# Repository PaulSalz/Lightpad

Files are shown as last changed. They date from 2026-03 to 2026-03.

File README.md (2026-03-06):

<div align="center">
<h1 align="center"><b>LightPad</b></h1>
DIY MIDI Controller to use with the Midi2LR Plugin

<picture>
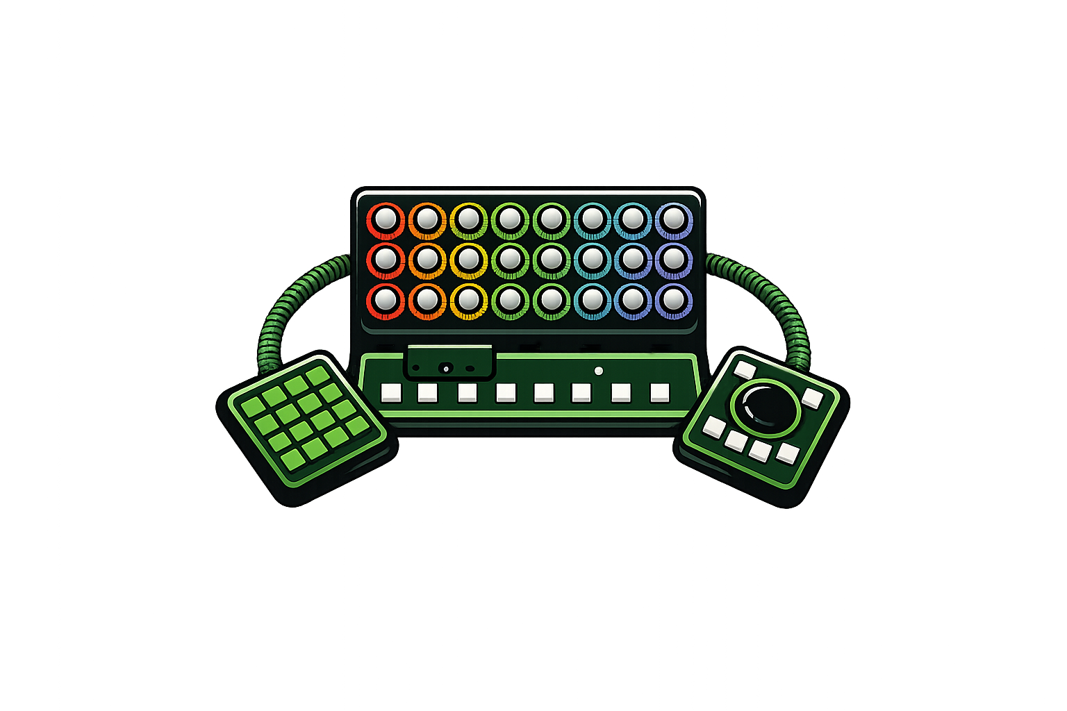
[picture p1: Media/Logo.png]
LightPad_Logo

</picture>
</div>
<br>

<picture>

</picture>

# Main features
- **[24x Interrupt-Driven Encoders](https://github.com/PaulSalz/lightpad/blob/main/Media/test_enc_led.jpg)**  
     - 3x8 RGB-illuminated Push-Button Encoders for all the main sliders, Lights, HSl, Details, ColorGrading, Effects...
- **[4x4 Button Matrix](https://github.com/PaulSalz/lightpad/blob/main/Media/top_view.jpg)**  
     - 16x RGB Buttons for easy Preset, Shortcut access
- **[Main Module](https://github.com/PaulSalz/lightpad/blob/main/Media/test_all.jpg)**  
     - 2x8 Buttons for switching Layers and often used features
- **[Media/ Culling Pad](https://github.com/PaulSalz/lightpad/blob/main/Media/side_view.jpg)**  
     - 8x RGB Buttons and an ANO Directional Navigation and Scroll Wheel to cull and navigate your library
- **[Force Feedback](https://github.com/PaulSalz/lightpad/blob/main/Media/test_all.jpg)**  
     - Integrated ERM Motor with DRV2605L for easy haptic effects 
- **[IR Remote Control](https://github.com/PaulSalz/lightpad/blob/main/Media/test_all.jpg)**  
     - Sometimes stepping back and cull from a distance helps me with culling
- **[Easy to print dual color case](https://www.rosa3d.pl/)**  
    - all printed from Rosa3D-Filaments PETG 
- **[Low/ High power mode](https://github.com/PaulSalz/lightpad/blob/main/Hardware/LightPad_BOM.html)**  
    - Full brightness gets unlocked with a external 5V source, and a mechanical switch on the main controller to prevent brown outs
- **[Animations]()**  
    - Idle animation
    - Button/ Encoder Effects
    - Backside illumination
- **[EL-Facts](https://github.com/PaulSalz/lightpad/blob/main/Media/usecase.jpg)**
    - Teensy 4.1 based
    - resettable fuses for both power inputs
    - RT1985N-A Protection IC for Softstart (needs some work)
    - I²C Level Shift 
    - Dual 74HC2G34 Buffer Gate for the LED's (using DMA)
    - expansion header for a Touch SPI Screen
    - all inputs connected through MCP23017 I/O expanders
  
<br>
<div align="center">
     
<picture>
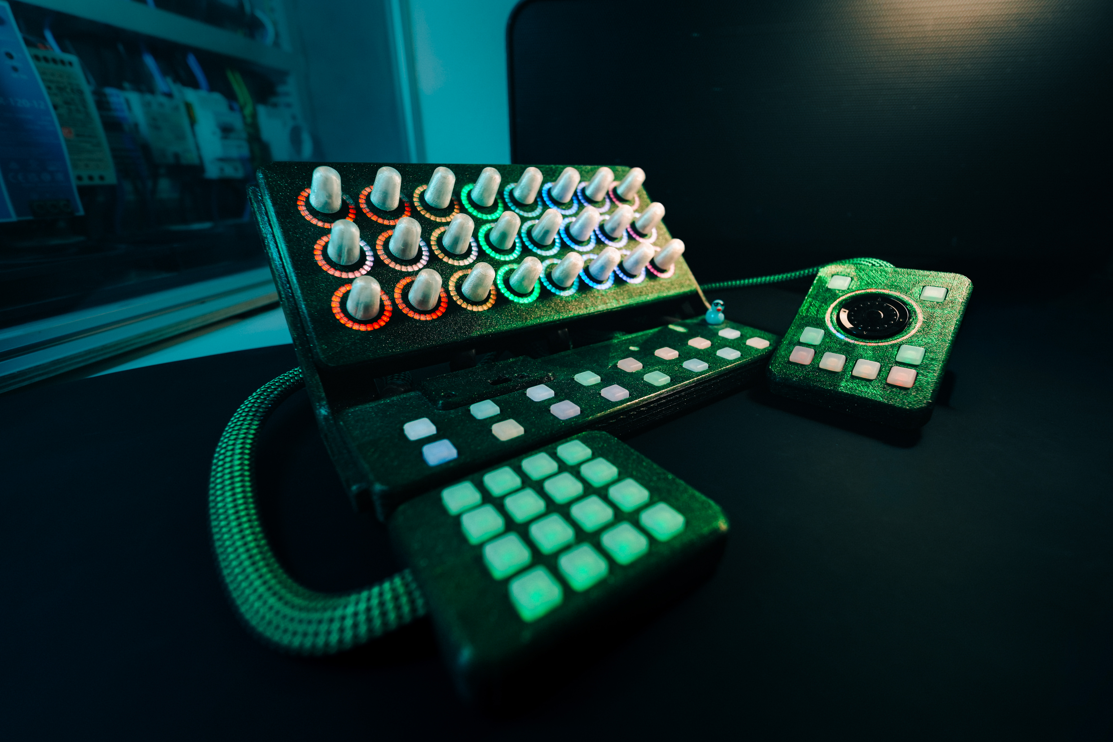
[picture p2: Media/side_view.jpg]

</picture>
<picture>
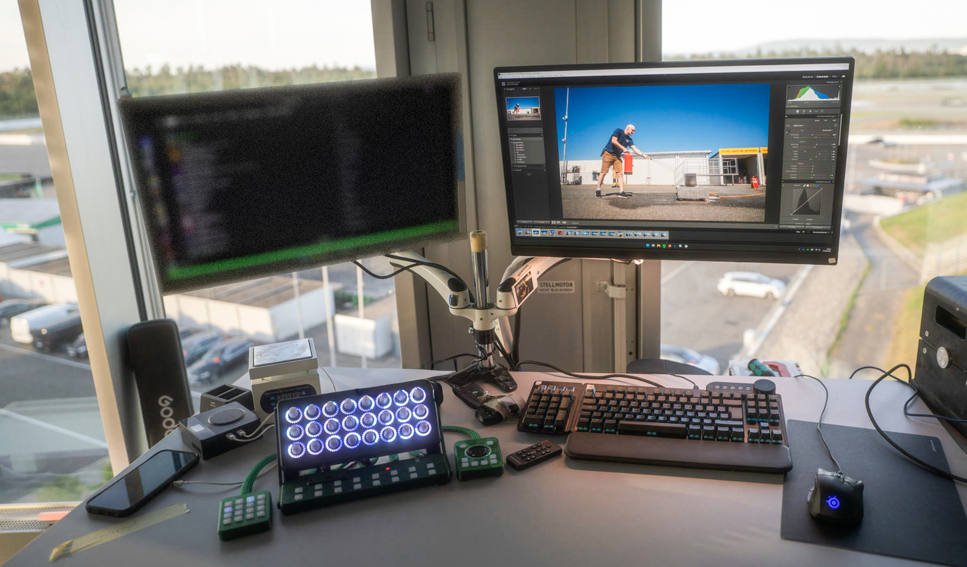
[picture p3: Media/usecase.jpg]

</picture>
<picture>

</picture>
     
</div>
<br>

## TO-DO
  - fix all the bugs that occurred during assembly
  - rewrite the code so everything can be configured on the fly without reflashing
  - ...

## Background
- In the past I used a Behringer X-Touch mini for editing with Lightroom Classic and although this worked somewhat great enough to convince colleagues to also get one I wanted more, having to constantly switch layers, modes and remembering all of them to find the right settings annoyed me and gave me the motivation for this. 
  There are other great options out there but I wanted something without proprietary software that maybe gets bricked in the future. and i wanted something fancy, something completly over the top, do you need that many LED's? hell no..  But they definitely help a lot with remembering all the functions and look awesome.

## Disclaimer
- This is a first try on a DIY Midi controller that was created roughly in a span of a month from idea to actually getting used.  
- There will be and there are bugs, for example part of the pcb's need a bit of rework and changes to work out of the box.

<br>
<div align="center">
     
<picture>
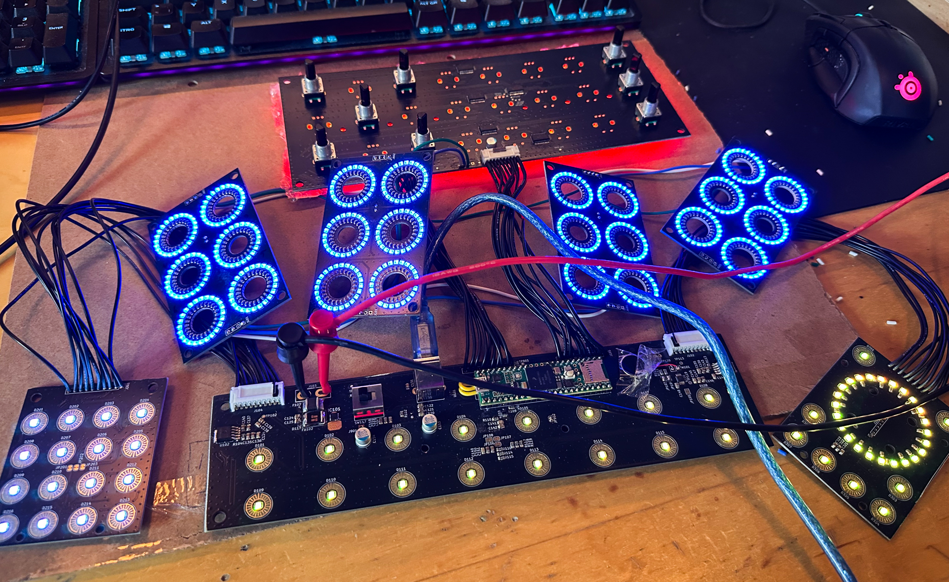
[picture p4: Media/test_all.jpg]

</picture>
<picture>
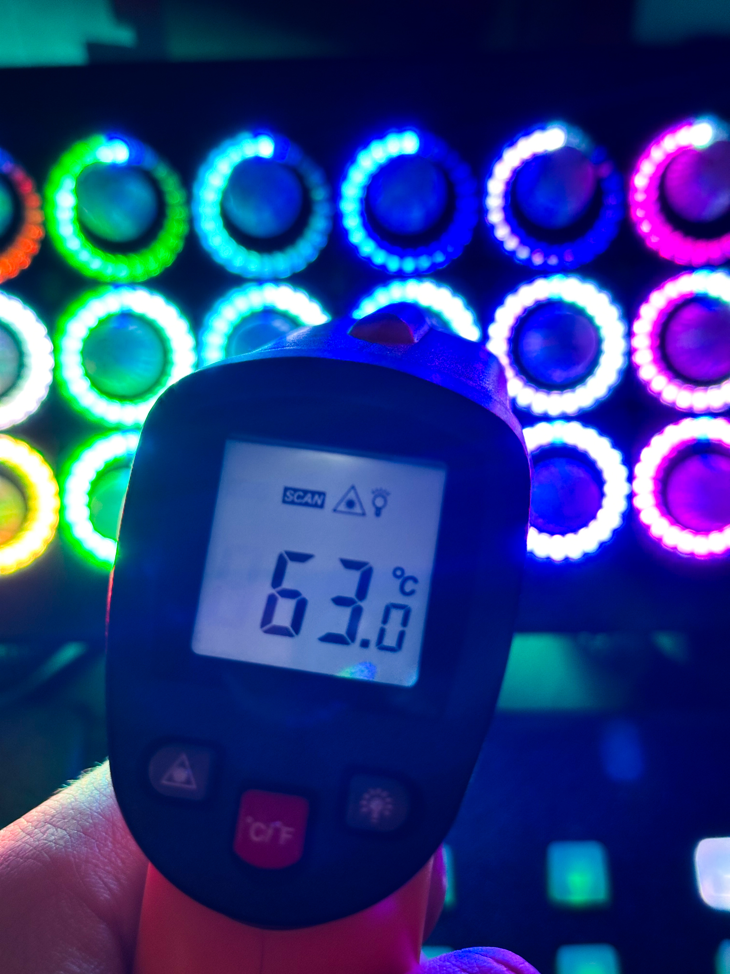
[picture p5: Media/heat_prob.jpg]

</picture>
     
</div>
<br>

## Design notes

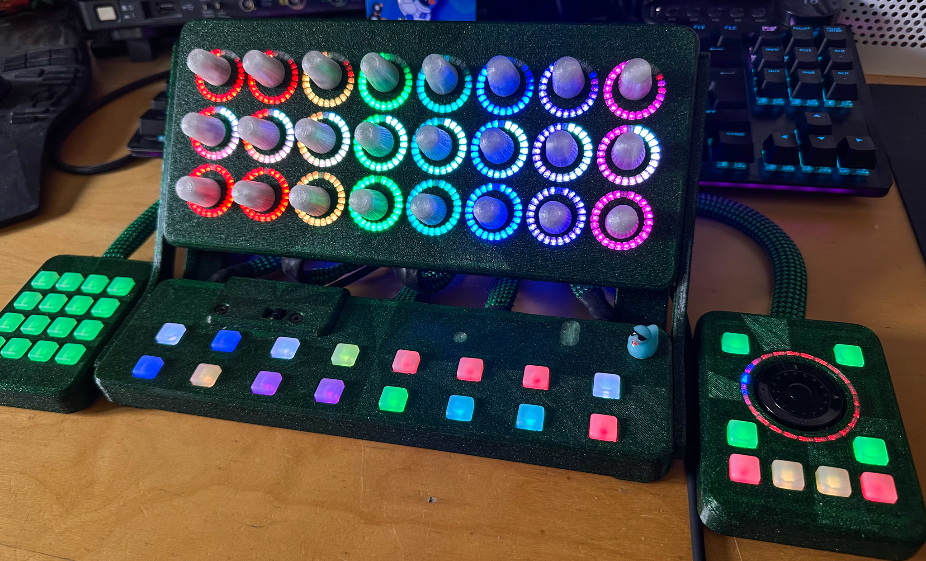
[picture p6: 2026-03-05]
Media/finished case.jpg

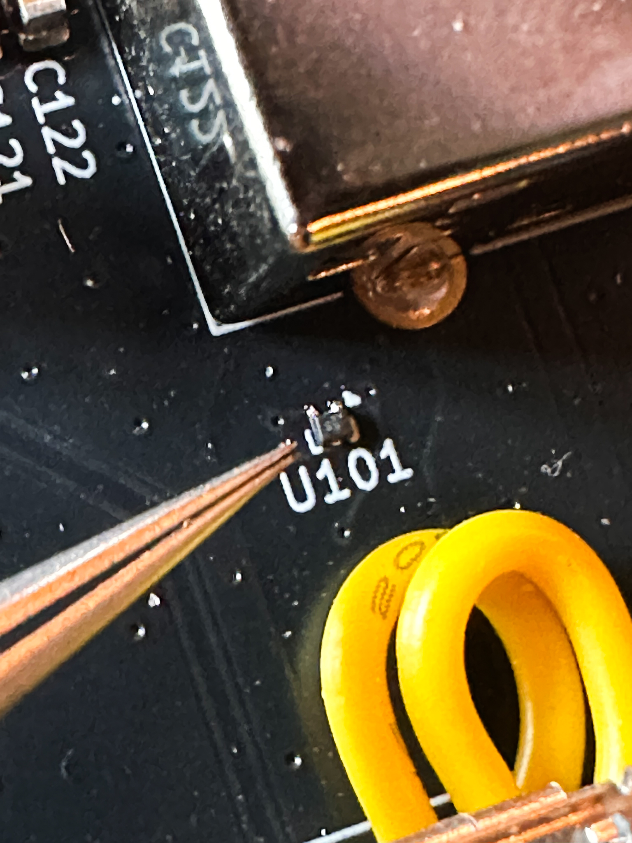
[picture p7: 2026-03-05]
Media/smallest comp.jpg

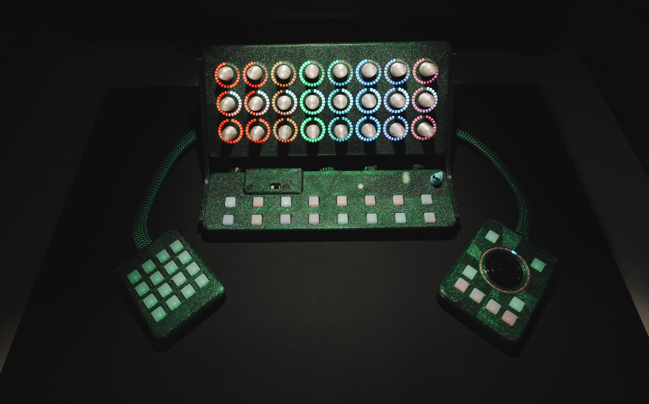
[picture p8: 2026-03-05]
Media/top_view.jpg

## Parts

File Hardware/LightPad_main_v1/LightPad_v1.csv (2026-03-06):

Reference | Value | Footprint | Datasheet | Beschreibung | Qty | DNP | Exclude from BOM | Exclude from Board
C101,C102,C103,C104,C105,C106,C107,C108,C109,C110,C111,C112,C113,C114,C115,C116,C117,C120,C131,C132,C134,C138,C141,C145,C149,C152,C155,C201,C202,C203,C204,C205,C206,C207,C208,C209,C210,C211,C212,C213,C214,C215,C216,C217,C301,C302,C303,C304,C305,C306,C307,C308,C321,C401,C402,C403,C404,C405,C406,C407,C408,C409,C410,C411,C412,C413,C414,C415,C416,C417,C418,C419,C420,C421,C422,C423,C424,C425,C426,C427,C428,C429,C430,C431,C432,C433,C434,C435,C436,C437,C438,C439,C440,C441,C442,C443,C444,C445,C446,C447,C448,C449,C450,C451,C452,C453,C454,C455,C456,C457,C458,C459,C460,C461,C462,C463,C464,C465,C466,C467,C468,C469,C470,C471,C472,C473,C474,C475,C476,C477,C478,C479,C480,C481,C482,C483,C484,C485,C486,C487,C488,C489,C490,C491,C492,C493,C494,C495,C496,C497,C500,C503,C506,C509,C601,C602,C603,C604,C605,C606,C607,C608,C609,C610,C611,C612,C613,C614,C615,C616,C617,C618,C619,C620,C621,C622,C623,C624,C625,C626,C627,C628,C629,C630,C631,C632,C633,C634,C635,C636,C637,C638,C639,C640,C641,C642,C643,C644,C645,C646,C647,C648,C649,C650,C651,C652,C653,C654,C655,C656,C657,C658,C659,C660,C661,C662,C663,C664,C665,C666,C667,C668,C669,C670,C671,C672,C673,C674,C675,C676,C677,C678,C679,C680,C681,C682,C683,C684,C685,C686,C687,C688,C689,C690,C691,C692,C693,C694,C695,C696,C697,C698,C699,C700,C701,C702,C703,C704,C705,C706,C707,C708,C709,C710,C711,C712,C713,C714,C715,C716,C717,C718,C719,C720,C721,C722,C723,C724,C725,C726,C727,C728,C729,C730,C731,C732,C733,C734,C735,C736,C737,C738,C739,C740,C741,C742,C743,C744,C745,C74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 | 0,1uF | Capacitor_SMD:C_0805_2012Metric | https://content.kemet.com/datasheets/KEM_C1002_X7R_SMD.pdf | C0805C104J5RAC7210 | 466
C118,C121,C123,C125,C127,C129,C136,C140,C146,C150,C156,C218,C322,C498,C501,C504,C507,C510 | 10uF | Capacitor_SMD:C_0805_2012Metric | ~ | CL21B106KOQNNNG | 18
C119,C122,C124,C126,C133,C135,C139,C142,C143,C147,C148,C151,C219,C323,C499,C502,C505,C508,C511 | 1uF | Capacitor_SMD:C_0805_2012Metric | https://content.kemet.com/datasheets/KEM_C1090_X7R_ESD.pdf | C0805C105J3RECTU | 19
C128,C130 | 1nF | Capacitor_SMD:C_0805_2012Metric |  | C0805C104J5RAC7210 | 2
C137,C144 | 10nF | Capacitor_SMD:C_0805_2012Metric | https://content.kemet.com/datasheets/KEM_C1002_X7R_SMD.pdf | C0805C103J5RAC7210 | 2
C153,C154 | APXE100ARA471MJ80G | My_Foots:CHEMI-J80 | ~ | Polarized capacitor | 2
D101,D102,D103,D104,D105,D106,D107,D108,D109,D110,D111,D112,D113,D114,D115,D116,D201,D202,D203,D204,D205,D206,D207,D208,D209,D210,D211,D212,D213,D214,D215,D216,D301,D302,D303,D304,D305,D306,D307,D308,D401,D402,D403,D404,D405,D406,D407,D408,D409,D410,D411,D412,D413,D414,D415,D416,D417,D418,D419,D420,D421,D422,D423,D424,D425,D426,D427,D428,D429,D430,D431,D432,D433,D434,D435,D436,D437,D438,D439,D440,D441,D442,D443,D444,D445,D446,D447,D448,D449,D450,D451,D452,D453,D454,D455,D456,D457,D458,D459,D460,D461,D462,D463,D464,D465,D466,D467,D468,D469,D470,D471,D472,D473,D474,D475,D476,D477,D478,D479,D480,D481,D482,D483,D484,D485,D486,D487,D488,D489,D490,D491,D492,D493,D494,D495,D496,D601,D602,D603,D604,D605,D606,D607,D608,D609,D610,D611,D612,D613,D614,D615,D616,D617,D618,D619,D620,D621,D622,D623,D624,D625,D626,D627,D628,D629,D630,D631,D632,D633,D634,D635,D636,D637,D638,D639,D640,D641,D642,D643,D644,D645,D646,D647,D648,D649,D650,D651,D652,D653,D654,D655,D656,D657,D658,D659,D660,D661,D662,D663,D664,D665,D666,D667,D668,D669,D670,D671,D672,D673,D674,D675,D676,D677,D678,D679,D680,D681,D682,D683,D684,D685,D686,D687,D688,D689,D690,D691,D692,D693,D694,D695,D696,D697,D698,D699,D700,D701,D702,D703,D704,D705,D706,D707,D708,D709,D710,D711,D712,D713,D714,D715,D716,D717,D718,D719,D720,D721,D722,D723,D724,D725,D726,D727,D728,D729,D730,D731,D732,D733,D734,D735,D736,D737,D738,D739,D740,D741,D742,D743,D744,D745,D746,D747,D748,D749,D750,D751,D752,D753,D754,D755,D756,D757,D758,D759,D760,D761,D762,D763,D76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 | WS2812B | My_Foots:LED_WS2812B-2020_PLCC4_2.0x2.0mm | https://cdn-shop.adafruit.com/product-files/4684/4684_WS2812B-2020_V1.3_EN.pdf | RGB LED with integrated controller, 2.0 x 2.0 mm, 12 mA | 448
D117,D118 | PESD5V0S1UL,315 | Diode_SMD:D_SOD-523 | https://www.onsemi.com/pdf/datasheet/esd5z2.5t1-d.pdf |  | 2
EN401,EN402,EN403,EN404,EN405,EN406,EN407,EN408,EN409,EN410,EN411,EN412,EN413,EN414,EN415,EN416,EN417,EN418,EN419,EN420,EN421,EN422,EN423,EN424 | RotaryEncoder_Switch | My_Foots:RotaryEncoder_Bourns_Vertical_PEC12R-3x17F-Sxxxx | https://www.bourns.com/docs/Product-Datasheets/PEC12R.pdf |  | 24
F101 | MICROSMD050F-2 | Resistor_SMD:R_1210_3225Metric_Pad1.30x2.65mm_HandSolder | https://www.yageo.com/upload/media/product/products/datasheet/cpc/pptc/SMD2920_1.pdf |  | 1
F102 | SMD2920B500TF | Fuse:Fuse_2920_7451Metric_Pad2.10x5.45mm_HandSolder | https://www.littelfuse.com/assetdocs/littelfuse-ptc-microsmd-datasheet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 |  | 1
FB101,FB102 | FerriteBead5650 | My_Foots:HI2220P701R-10 | https://www.laird.com/sites/default/files/hi2220p701r-10-datasheet.pdf |  | 2
HS101,HS102 | Heatsink_Pad |  | ~ | Heatsink with electrical connection, 1 pin | 2 |  |  | Excluded from board
IC101,IC102 | RT1985N-A | RT1985NA | https://www.richtek.com/assets/product_file/RT1985/RT1985_DS-00.pdf | Hot Swap Voltage Controllers 23V/8A Ideal Diode Protection Switch | 2
J101 | USB_B | Connector_USB:USB_B_Lumberg_2411_02_Horizontal | https://gct.co/files/specs/usb1030-spec.pdf |  | 1
J102,J104,J402,J403 | Conn_01x10 | My_Foots:JST_PH_S10B-PH-K_1x10_P2.00mm_Horizontal | https://www.jst-mfg.com/product/pdf/eng/ePH.pdf |  | 4
J103 | Barrel_Jack | My_Foots:power conn | https://www.sameskydevices.com/product/resource/pj-039bh.pdf |  | 1
J105,J106,J201,J301 | Conn_01x10 | Connector_PinHeader_2.54mm:PinHeader_1x10_P2.54mm_Vertical | https://www.jst-mfg.com/product/pdf/eng/ePH.pdf |  | 4
J303 | Conn_01x09_Socket | Connector_PinSocket_2.00mm:PinSocket_1x09_P2.00mm_Vertical | ~ | Generic connector, single row, 01x09, script generated | 1
J401 | Conn_01x10 | Connector_JST:JST_PH_S10B-PH-K_1x10_P2.00mm_Horizontal | https://www.jst-mfg.com/product/pdf/eng/ePH.pdf |  | 1 | DNP |  | Excluded from board
J601,J602,J603,J604,J605 | Conn_01x04_Socket | Connector_PinSocket_2.54mm:PinSocket_1x04_P2.54mm_Vertical | ~ | Generic connector, single row, 01x04, script generated | 5
JP101,JP102,JP103,JP104,JP105,JP108,JP301,JP302,JP303,JP402,JP403,JP404,JP405,JP407,JP409,JP411,JP413 | Jumper_2_Open | Jumper:SolderJumper-2_P1.3mm_Open_TrianglePad1.0x1.5mm | ~ |  | 17
JP106,JP107,JP201,JP202,JP203,JP401,JP406,JP408,JP410,JP412,JP414,JP415 | Jumper_2_Bridged | Jumper:SolderJumper-2_P1.3mm_Bridged_RoundedPad1.0x1.5mm | ~ |  | 12
L101 | 744231091 | My_Foots:WE-CNSW_0805 | https://www.we-online.com/components/products/datasheet/744231091.pdf |  | 1
M101 | Motor_DC | Connector_PinHeader_2.54mm:PinHeader_1x02_P2.54mm_Vertical | https://mm.digikey.com/Volume0/opasdata/d220001/medias/docus/5564/JYC1234.pdf |  | 1
Q101,Q102 | BSS138 | Package_TO_SOT_SMD:SOT-23 | https://www.onsemi.com/pub/Collateral/BSS138-D.PDF |  | 2
R101,R102,R103,R104,R105,R106,R107,R108,R111,R112,R113,R114,R115,R116,R117,R118,R119,R201,R202,R203,R204,R205,R206,R301,R302,R303,R304,R305,R306,R401,R402,R403,R404,R405,R406,R407,R408,R409,R410,R411,R412,R413,R414,R415,R416,R417,R418,R419,R420,R421,R422,R423,R424,R425,R426,R427,R428,R429,R430 | 10k | Resistor_SMD:R_0805_2012Metric | https://www.seielect.com/catalog/sei-rmcf_rmcp.pdf | RMCP0805JT10K0 | 59
R109,R110 | 100 | Resistor_SMD:R_0805_2012Metric | ~https://www.te.com/usa-en/product-9-1879508-7.datasheet.pdf |  | 2
Sc/NavWheel301 | ~ | My_Foots:navscroll wheel_dummy | https://www.digikey.de/de/products/detail/adafruit-industries-llc/5001/15277532 |  | 1 | DNP
SW101,SW102,SW103,SW104,SW105,SW106,SW107,SW108,SW109,SW110,SW111,SW112,SW113,SW114,SW115,SW116,SW201,SW202,SW203,SW204,SW205,SW206,SW207,SW208,SW209,SW210,SW211,SW212,SW213,SW214,SW215,SW216,SW301,SW302,SW303,SW304,SW305,SW306,SW307,SW308 | SW_Push | My_Foots:button rubber | https://www.digikey.de/de/products/detail/adafruit-industries-llc/1611/5823361 |  | 40
SW117 | SW_Push_DPDT | My_Foots:MFP 226 Switch | www.digikey.de/de/products/detail/knitter-switch/MFP-226-P-PC/26485776 |  | 1
TP3V1,TP5V1,TP101,TP102,TP103,TP104,TP105,TP113,TP119,TP120,TP121,TP122,TP123,TP124,TP125,TP134,TP135,TPD_in1,TPD_in745,TPD_in746,TP_Dout1,TP_SCL1,TP_SDA1 | TestPoint_Small | TestPoint:TestPoint_Pad_D1.0mm | ~ |  | 23
TP92,TP93,TP94,TP95,TP126,TP127,TP128,TP129,TP130,TP131,TP132,TP133,TP401,TP402,TP403,TP404,TP405,TP406,TP407,TP408 | TestPoint_Small | TestPoint:TestPoint_Pad_D1.0mm | ~ |  | 20 | DNP |  | Excluded from board
TP106,TP107,TP108,TP109,TP110,TP111,TP112,TP114,TP115,TP116,TP117,TP118 | TestPoint_Small | TestPoint:TestPoint_Pad_1.0x1.0mm | ~ |  | 12 | DNP |  | Excluded from board
TP301 | TestPoint_Small | TestPoint:TestPoint_THTPad_D1.5mm_Drill0.7mm | ~ | test point | 1
U101 | TPD2EUSB30ADRTR | Package_TO_SOT_SMD:Texas_DRT-3 | http://www.ti.com/lit/ds/symlink/tpd2eusb30a.pdf |  | 1
U102,U107 | NJM2884 | Package_TO_SOT_SMD:TO-252-5_TabPin3 | www.nisshinbo-microdevices.co.jp/en/pdf/datasheet/NJM2884_2884A_E.pdf |  | 2
U103 | Teensy4.1 | My_Foots:Teensy41 | https://www.pjrc.com/ |  | 1
U104 | 74HCT2G34GW_125 | My_Foots:SC-88_SOT363_NEX | https://assets.nexperia.com/documents/data-sheet/74HC_HCT2G34.pdf |  | 1
U105 | CR2013-MI2120 | Display:CR2013-MI2120 | http://pan.baidu.com/s/11Y990 | ILI9341 controller, SPI TFT LCD Display, 9-pin breakout PCB, 4-pin SD card interface, 5V/3.3V | 1 | DNP |  | Excluded from board
U106 | DRV2605LDGS | Package_SO:VSSOP-10_3x3mm_P0.5mm | http://www.ti.com/lit/ds/symlink/drv2605l.pdf |  | 1
U108,U201,U301,U401,U402,U403,U404,U405 | MCP23017_SS | Package_SO:SSOP-28_5.3x10.2mm_P0.65mm | http://ww1.microchip.com/downloads/en/DeviceDoc/20001952C.pdf |  | 8

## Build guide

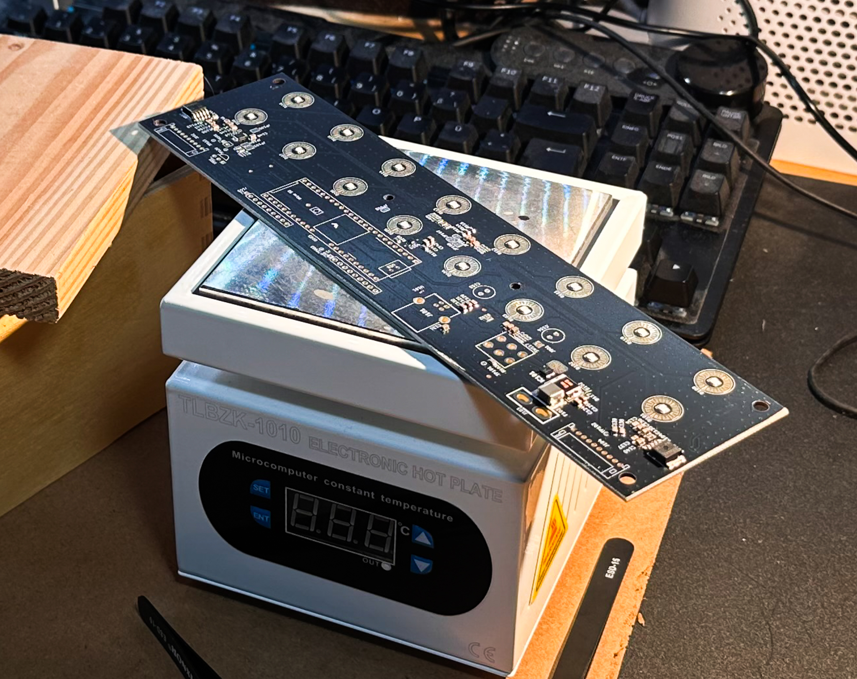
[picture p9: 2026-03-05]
Media/main_soldering.jpg

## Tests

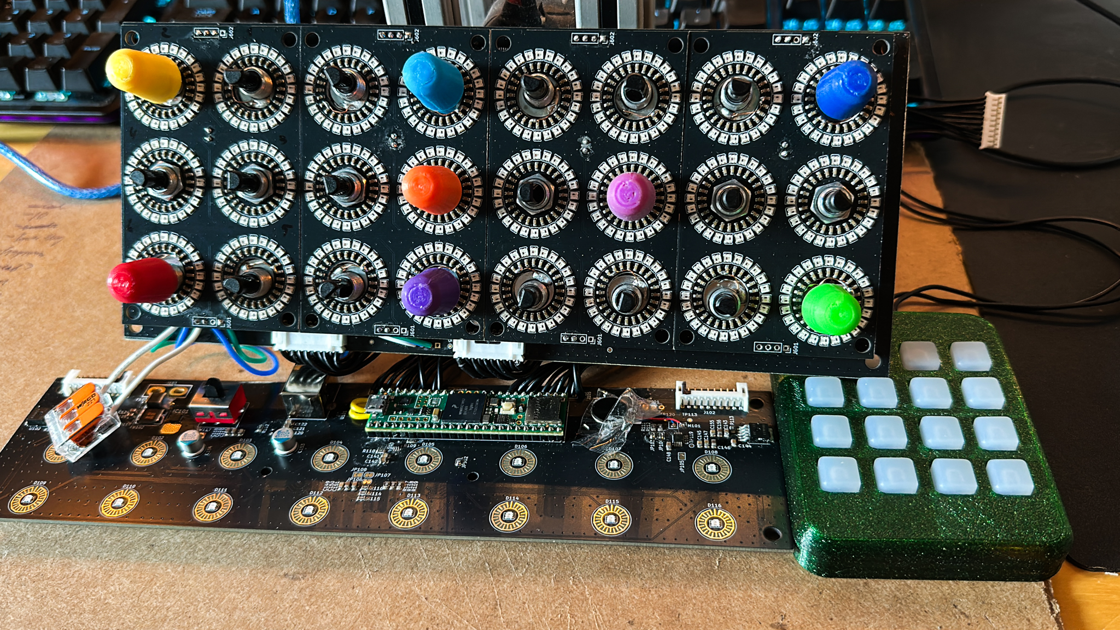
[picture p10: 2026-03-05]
Media/testing.jpg

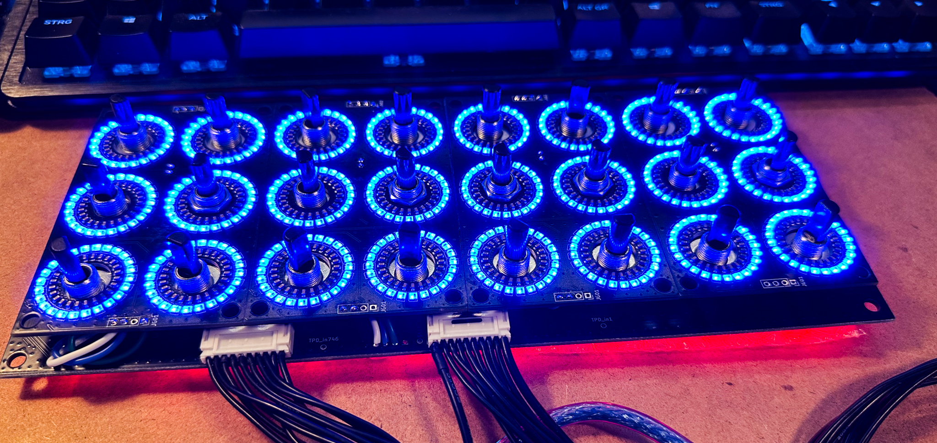
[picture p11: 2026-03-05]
Media/test_enc_led.jpg

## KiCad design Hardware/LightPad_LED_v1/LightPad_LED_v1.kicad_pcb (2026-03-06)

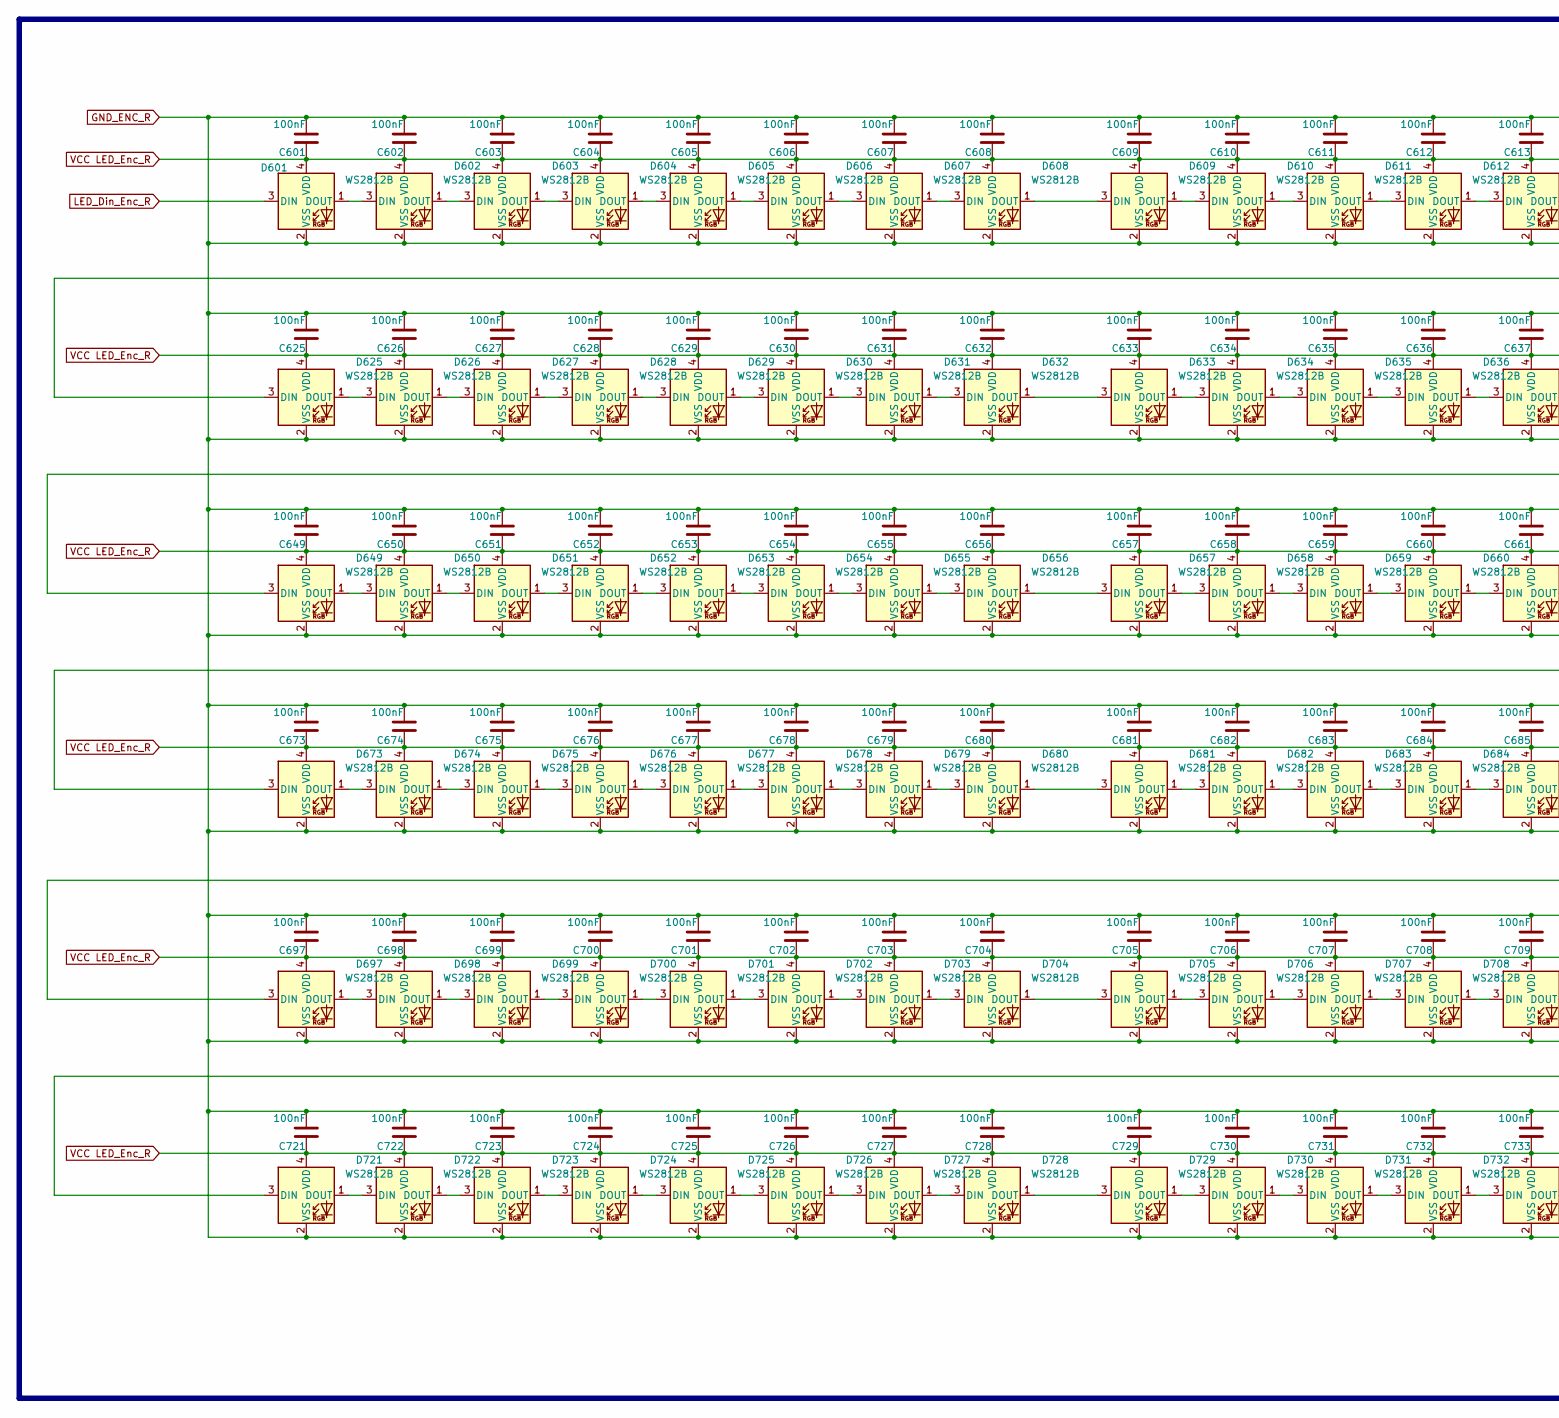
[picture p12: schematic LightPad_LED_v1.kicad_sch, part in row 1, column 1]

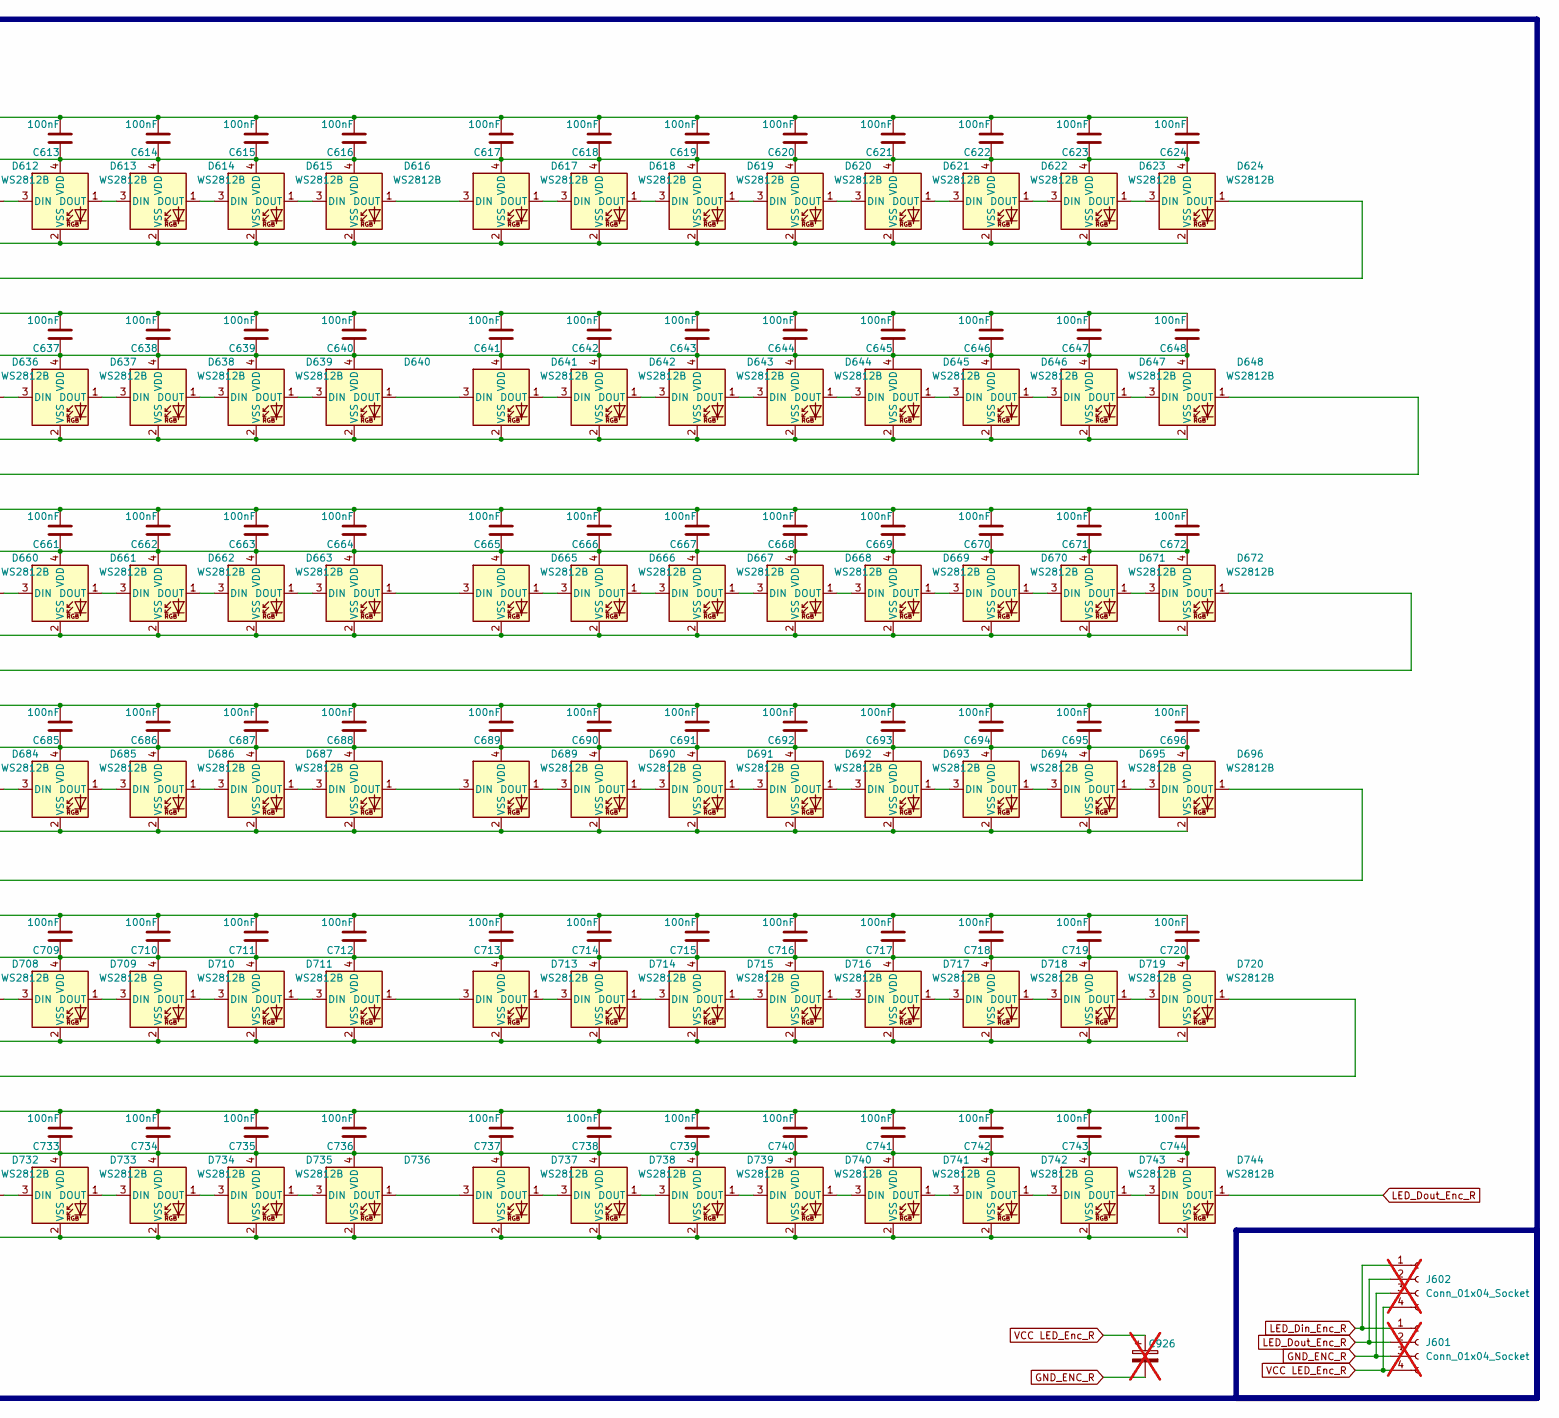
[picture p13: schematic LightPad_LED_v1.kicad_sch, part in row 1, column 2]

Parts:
C601, C602, C603, C604, C605, C606, C607, C608, C609, C610, C611, C612, C613, C614, C615, C616, C617, C618, C619, C620, C621, C622, C623, C624, C625, C626, C627, C628, C629, C630, C631, C632, C633, C634, C635, C636, C637, C638, C639, C640, C641, C642, C643, C644, C645, C646, C647, C648, C649, C650, C651, C652, C653, C654, C655, C656, C657, C658, C659, C660, C661, C662, C663, C664, C665, C666, C667, C668, C669, C670, C671, C672, C673, C674, C675, C676, C677, C678, C679, C680, C681, C682, C683, C684, C685, C686, C687, C688, C689, C690, C691, C692, C693, C694, C695, C696, C697, C698, C699, C700, C701, C702, C703, C704, C705, C706, C707, C708, C709, C710, C711, C712, C713, C714, C715, C716, C717, C718, C719, C720, C721, C722, C723, C724, C725, C726, C727, C728, C729, C730, C731, C732, C733, C734, C735, C736, C737, C738, C739, C740, C741, C742, C743, C744: 100nF; C_0603_1608Metric; LCSC C24452
C926: APXE100ARA471MJ80G; C_Radial_D6.3mm_H5.0mm_P2.50mm; not fitted
D601, D602, D603, D604, D605, D606, D607, D608, D609, D610, D611, D612, D613, D614, D615, D616, D617, D618, D619, D620, D621, D622, D623, D624, D625, D626, D627, D628, D629, D630, D631, D632, D633, D634, D635, D636, D637, D638, D639, D640, D641, D642, D643, D644, D645, D646, D647, D648, D649, D650, D651, D652, D653, D654, D655, D656, D657, D658, D659, D660, D661, D662, D663, D664, D665, D666, D667, D668, D669, D670, D671, D672, D673, D674, D675, D676, D677, D678, D679, D680, D681, D682, D683, D684, D685, D686, D687, D688, D689, D690, D691, D692, D693, D694, D695, D696, D697, D698, D699, D700, D701, D702, D703, D704, D705, D706, D707, D708, D709, D710, D711, D712, D713, D714, D715, D716, D717, D718, D719, D720, D721, D722, D723, D724, D725, D726, D727, D728, D729, D730, D731, D732, D733, D734, D735, D736, D737, D738, D739, D740, D741, D742, D743, D744: WS2812B; LED_WS2812B-2020_PLCC4_2.0x2.0mm; LCSC C965555
J601, J602: Conn_01x04_Socket; PinSocket_1x04_P2.54mm_Vertical; not fitted

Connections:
GND_ENC_R: C601.1, C602.1, C603.1, C604.1, C605.1, C606.1, C607.1, C608.1, C609.1, C610.1, C611.1, C612.1, C613.1, C614.1, C615.1, C616.1, C617.1, C618.1, C619.1, C620.1, C621.1, C622.1, C623.1, C624.1, C625.1, C626.1, C627.1, C628.1, C629.1, C630.1, C631.1, C632.1, C633.1, C634.1, C635.1, C636.1, C637.1, C638.1, C639.1, C640.1, C641.1, C642.1, C643.1, C644.1, C645.1, C646.1, C647.1, C648.1, C649.1, C650.1, C651.1, C652.1, C653.1, C654.1, C655.1, C656.1, C657.1, C658.1, C659.1, C660.1, C661.1, C662.1, C663.1, C664.1, C665.1, C666.1, C667.1, C668.1, C669.1, C670.1, C671.1, C672.1, C673.1, C674.1, C675.1, C676.1, C677.1, C678.1, C679.1, C680.1, C681.1, C682.1, C683.1, C684.1, C685.1, C686.1, C687.1, C688.1, C689.1, C690.1, C691.1, C692.1, C693.1, C694.1, C695.1, C696.1, C697.1, C698.1, C699.1, C700.1, C701.1, C702.1, C703.1, C704.1, C705.1, C706.1, C707.1, C708.1, C709.1, C710.1, C711.1, C712.1, C713.1, C714.1, C715.1, C716.1, C717.1, C718.1, C719.1, C720.1, C721.1, C722.1, C723.1, C724.1, C725.1, C726.1, C727.1, C728.1, C729.1, C730.1, C731.1, C732.1, C733.1, C734.1, C735.1, C736.1, C737.1, C738.1, C739.1, C740.1, C741.1, C742.1, C743.1, C744.1, C926.2, D601.2 (VSS), D602.2 (VSS), D603.2 (VSS), D604.2 (VSS), D605.2 (VSS), D606.2 (VSS), D607.2 (VSS), D608.2 (VSS), D609.2 (VSS), D610.2 (VSS), D611.2 (VSS), D612.2 (VSS), D613.2 (VSS), D614.2 (VSS), D615.2 (VSS), D616.2 (VSS), D617.2 (VSS), D618.2 (VSS), D619.2 (VSS), D620.2 (VSS), D621.2 (VSS), D622.2 (VSS), D623.2 (VSS), D624.2 (VSS), D625.2 (VSS), D626.2 (VSS), D627.2 (VSS), D628.2 (VSS), D629.2 (VSS), D630.2 (VSS), D631.2 (VSS), D632.2 (VSS), D633.2 (VSS), D634.2 (VSS), D635.2 (VSS), D636.2 (VSS), D637.2 (VSS), D638.2 (VSS), D639.2 (VSS), D640.2 (VSS), D641.2 (VSS), D642.2 (VSS), D643.2 (VSS), D644.2 (VSS), D645.2 (VSS), D646.2 (VSS), D647.2 (VSS), D648.2 (VSS), D649.2 (VSS), D650.2 (VSS), D651.2 (VSS), D652.2 (VSS), D653.2 (VSS), D654.2 (VSS), D655.2 (VSS), D656.2 (VSS), D657.2 (VSS), D658.2 (VSS), D659.2 (VSS), D660.2 (VSS), D661.2 (VSS), D662.2 (VSS), D663.2 (VSS), D664.2 (VSS), D665.2 (VSS), D666.2 (VSS), D667.2 (VSS), D668.2 (VSS), D669.2 (VSS), D670.2 (VSS), D671.2 (VSS), D672.2 (VSS), D673.2 (VSS), D674.2 (VSS), D675.2 (VSS), D676.2 (VSS), D677.2 (VSS), D678.2 (VSS), D679.2 (VSS), D680.2 (VSS), D681.2 (VSS), D682.2 (VSS), D683.2 (VSS), D684.2 (VSS), D685.2 (VSS), D686.2 (VSS), D687.2 (VSS), D688.2 (VSS), D689.2 (VSS), D690.2 (VSS), D691.2 (VSS), D692.2 (VSS), D693.2 (VSS), D694.2 (VSS), D695.2 (VSS), D696.2 (VSS), D697.2 (VSS), D698.2 (VSS), D699.2 (VSS), D700.2 (VSS), D701.2 (VSS), D702.2 (VSS), D703.2 (VSS), D704.2 (VSS), D705.2 (VSS), D706.2 (VSS), D707.2 (VSS), D708.2 (VSS), D709.2 (VSS), D710.2 (VSS), D711.2 (VSS), D712.2 (VSS), D713.2 (VSS), D714.2 (VSS), D715.2 (VSS), D716.2 (VSS), D717.2 (VSS), D718.2 (VSS), D719.2 (VSS), D720.2 (VSS), D721.2 (VSS), D722.2 (VSS), D723.2 (VSS), D724.2 (VSS), D725.2 (VSS), D726.2 (VSS), D727.2 (VSS), D728.2 (VSS), D729.2 (VSS), D730.2 (VSS), D731.2 (VSS), D732.2 (VSS), D733.2 (VSS), D734.2 (VSS), D735.2 (VSS), D736.2 (VSS), D737.2 (VSS), D738.2 (VSS), D739.2 (VSS), D740.2 (VSS), D741.2 (VSS), D742.2 (VSS), D743.2 (VSS), D744.2 (VSS), J601.3, J602.3
LED_Din_Enc_R: D601.3 (DIN), J601.1, J602.1
LED_Dout_Enc_R: D744.1 (DOUT), J601.2, J602.2
unnamed: D601.1 (DOUT), D602.3 (DIN)
unnamed: D602.1 (DOUT), D603.3 (DIN)
unnamed: D603.1 (DOUT), D604.3 (DIN)
unnamed: D604.1 (DOUT), D605.3 (DIN)
unnamed: D605.1 (DOUT), D606.3 (DIN)
unnamed: D606.1 (DOUT), D607.3 (DIN)
unnamed: D607.1 (DOUT), D608.3 (DIN)
unnamed: D608.1 (DOUT), D609.3 (DIN)
unnamed: D609.1 (DOUT), D610.3 (DIN)
unnamed: D610.1 (DOUT), D611.3 (DIN)
unnamed: D611.1 (DOUT), D612.3 (DIN)
unnamed: D612.1 (DOUT), D613.3 (DIN)
unnamed: D613.1 (DOUT), D614.3 (DIN)
unnamed: D614.1 (DOUT), D615.3 (DIN)
unnamed: D615.1 (DOUT), D616.3 (DIN)
unnamed: D616.1 (DOUT), D617.3 (DIN)
unnamed: D617.1 (DOUT), D618.3 (DIN)
unnamed: D618.1 (DOUT), D619.3 (DIN)
unnamed: D619.1 (DOUT), D620.3 (DIN)
unnamed: D620.1 (DOUT), D621.3 (DIN)
unnamed: D621.1 (DOUT), D622.3 (DIN)
unnamed: D622.1 (DOUT), D623.3 (DIN)
unnamed: D623.1 (DOUT), D624.3 (DIN)
unnamed: D624.1 (DOUT), D625.3 (DIN)
unnamed: D625.1 (DOUT), D626.3 (DIN)
unnamed: D626.1 (DOUT), D627.3 (DIN)
unnamed: D627.1 (DOUT), D628.3 (DIN)
unnamed: D628.1 (DOUT), D629.3 (DIN)
unnamed: D629.1 (DOUT), D630.3 (DIN)
unnamed: D630.1 (DOUT), D631.3 (DIN)
unnamed: D631.1 (DOUT), D632.3 (DIN)
unnamed: D632.1 (DOUT), D633.3 (DIN)
unnamed: D633.1 (DOUT), D634.3 (DIN)
unnamed: D634.1 (DOUT), D635.3 (DIN)
unnamed: D635.1 (DOUT), D636.3 (DIN)
unnamed: D636.1 (DOUT), D637.3 (DIN)
unnamed: D637.1 (DOUT), D638.3 (DIN)
unnamed: D638.1 (DOUT), D639.3 (DIN)
unnamed: D639.1 (DOUT), D640.3 (DIN)
unnamed: D640.1 (DOUT), D641.3 (DIN)
unnamed: D641.1 (DOUT), D642.3 (DIN)
unnamed: D642.1 (DOUT), D643.3 (DIN)
unnamed: D643.1 (DOUT), D644.3 (DIN)
unnamed: D644.1 (DOUT), D645.3 (DIN)
unnamed: D645.1 (DOUT), D646.3 (DIN)
unnamed: D646.1 (DOUT), D647.3 (DIN)
unnamed: D647.1 (DOUT), D648.3 (DIN)
unnamed: D648.1 (DOUT), D649.3 (DIN)
unnamed: D649.1 (DOUT), D650.3 (DIN)
unnamed: D650.1 (DOUT), D651.3 (DIN)
unnamed: D651.1 (DOUT), D652.3 (DIN)
unnamed: D652.1 (DOUT), D653.3 (DIN)
unnamed: D653.1 (DOUT), D654.3 (DIN)
unnamed: D654.1 (DOUT), D655.3 (DIN)
unnamed: D655.1 (DOUT), D656.3 (DIN)
unnamed: D656.1 (DOUT), D657.3 (DIN)
unnamed: D657.1 (DOUT), D658.3 (DIN)
unnamed: D658.1 (DOUT), D659.3 (DIN)
unnamed: D659.1 (DOUT), D660.3 (DIN)
unnamed: D660.1 (DOUT), D661.3 (DIN)
unnamed: D661.1 (DOUT), D662.3 (DIN)
unnamed: D662.1 (DOUT), D663.3 (DIN)
unnamed: D663.1 (DOUT), D664.3 (DIN)
unnamed: D664.1 (DOUT), D665.3 (DIN)
unnamed: D665.1 (DOUT), D666.3 (DIN)
unnamed: D666.1 (DOUT), D667.3 (DIN)
unnamed: D667.1 (DOUT), D668.3 (DIN)
unnamed: D668.1 (DOUT), D669.3 (DIN)
unnamed: D669.1 (DOUT), D670.3 (DIN)
unnamed: D670.1 (DOUT), D671.3 (DIN)
unnamed: D671.1 (DOUT), D672.3 (DIN)
unnamed: D672.1 (DOUT), D673.3 (DIN)
unnamed: D673.1 (DOUT), D674.3 (DIN)
unnamed: D674.1 (DOUT), D675.3 (DIN)
unnamed: D675.1 (DOUT), D676.3 (DIN)
unnamed: D676.1 (DOUT), D677.3 (DIN)
unnamed: D677.1 (DOUT), D678.3 (DIN)
unnamed: D678.1 (DOUT), D679.3 (DIN)
unnamed: D679.1 (DOUT), D680.3 (DIN)
unnamed: D680.1 (DOUT), D681.3 (DIN)
unnamed: D681.1 (DOUT), D682.3 (DIN)
unnamed: D682.1 (DOUT), D683.3 (DIN)
unnamed: D683.1 (DOUT), D684.3 (DIN)
unnamed: D684.1 (DOUT), D685.3 (DIN)
unnamed: D685.1 (DOUT), D686.3 (DIN)
unnamed: D686.1 (DOUT), D687.3 (DIN)
unnamed: D687.1 (DOUT), D688.3 (DIN)
unnamed: D688.1 (DOUT), D689.3 (DIN)
unnamed: D689.1 (DOUT), D690.3 (DIN)
unnamed: D690.1 (DOUT), D691.3 (DIN)
unnamed: D691.1 (DOUT), D692.3 (DIN)
unnamed: D692.1 (DOUT), D693.3 (DIN)
unnamed: D693.1 (DOUT), D694.3 (DIN)
unnamed: D694.1 (DOUT), D695.3 (DIN)
unnamed: D695.1 (DOUT), D696.3 (DIN)
unnamed: D696.1 (DOUT), D697.3 (DIN)
unnamed: D697.1 (DOUT), D698.3 (DIN)
unnamed: D698.1 (DOUT), D699.3 (DIN)
unnamed: D699.1 (DOUT), D700.3 (DIN)
unnamed: D700.1 (DOUT), D701.3 (DIN)
unnamed: D701.1 (DOUT), D702.3 (DIN)
unnamed: D702.1 (DOUT), D703.3 (DIN)
unnamed: D703.1 (DOUT), D704.3 (DIN)
unnamed: D704.1 (DOUT), D705.3 (DIN)
unnamed: D705.1 (DOUT), D706.3 (DIN)
unnamed: D706.1 (DOUT), D707.3 (DIN)
unnamed: D707.1 (DOUT), D708.3 (DIN)
unnamed: D708.1 (DOUT), D709.3 (DIN)
unnamed: D709.1 (DOUT), D710.3 (DIN)
unnamed: D710.1 (DOUT), D711.3 (DIN)
unnamed: D711.1 (DOUT), D712.3 (DIN)
unnamed: D712.1 (DOUT), D713.3 (DIN)
unnamed: D713.1 (DOUT), D714.3 (DIN)
unnamed: D714.1 (DOUT), D715.3 (DIN)
unnamed: D715.1 (DOUT), D716.3 (DIN)
unnamed: D716.1 (DOUT), D717.3 (DIN)
unnamed: D717.1 (DOUT), D718.3 (DIN)
unnamed: D718.1 (DOUT), D719.3 (DIN)
unnamed: D719.1 (DOUT), D720.3 (DIN)
unnamed: D720.1 (DOUT), D721.3 (DIN)
unnamed: D721.1 (DOUT), D722.3 (DIN)
unnamed: D722.1 (DOUT), D723.3 (DIN)
unnamed: D723.1 (DOUT), D724.3 (DIN)
unnamed: D724.1 (DOUT), D725.3 (DIN)
unnamed: D725.1 (DOUT), D726.3 (DIN)
unnamed: D726.1 (DOUT), D727.3 (DIN)
unnamed: D727.1 (DOUT), D728.3 (DIN)
unnamed: D728.1 (DOUT), D729.3 (DIN)
unnamed: D729.1 (DOUT), D730.3 (DIN)
unnamed: D730.1 (DOUT), D731.3 (DIN)
unnamed: D731.1 (DOUT), D732.3 (DIN)
unnamed: D732.1 (DOUT), D733.3 (DIN)
unnamed: D733.1 (DOUT), D734.3 (DIN)
unnamed: D734.1 (DOUT), D735.3 (DIN)
unnamed: D735.1 (DOUT), D736.3 (DIN)
unnamed: D736.1 (DOUT), D737.3 (DIN)
unnamed: D737.1 (DOUT), D738.3 (DIN)
unnamed: D738.1 (DOUT), D739.3 (DIN)
unnamed: D739.1 (DOUT), D740.3 (DIN)
unnamed: D740.1 (DOUT), D741.3 (DIN)
unnamed: D741.1 (DOUT), D742.3 (DIN)
unnamed: D742.1 (DOUT), D743.3 (DIN)
unnamed: D743.1 (DOUT), D744.3 (DIN)
VCC LED_Enc_R: C601.2, C602.2, C603.2, C604.2, C605.2, C606.2, C607.2, C608.2, C609.2, C610.2, C611.2, C612.2, C613.2, C614.2, C615.2, C616.2, C617.2, C618.2, C619.2, C620.2, C621.2, C622.2, C623.2, C624.2, C625.2, C626.2, C627.2, C628.2, C629.2, C630.2, C631.2, C632.2, C633.2, C634.2, C635.2, C636.2, C637.2, C638.2, C639.2, C640.2, C641.2, C642.2, C643.2, C644.2, C645.2, C646.2, C647.2, C648.2, C649.2, C650.2, C651.2, C652.2, C653.2, C654.2, C655.2, C656.2, C657.2, C658.2, C659.2, C660.2, C661.2, C662.2, C663.2, C664.2, C665.2, C666.2, C667.2, C668.2, C669.2, C670.2, C671.2, C672.2, C673.2, C674.2, C675.2, C676.2, C677.2, C678.2, C679.2, C680.2, C681.2, C682.2, C683.2, C684.2, C685.2, C686.2, C687.2, C688.2, C689.2, C690.2, C691.2, C692.2, C693.2, C694.2, C695.2, C696.2, C697.2, C698.2, C699.2, C700.2, C701.2, C702.2, C703.2, C704.2, C705.2, C706.2, C707.2, C708.2, C709.2, C710.2, C711.2, C712.2, C713.2, C714.2, C715.2, C716.2, C717.2, C718.2, C719.2, C720.2, C721.2, C722.2, C723.2, C724.2, C725.2, C726.2, C727.2, C728.2, C729.2, C730.2, C731.2, C732.2, C733.2, C734.2, C735.2, C736.2, C737.2, C738.2, C739.2, C740.2, C741.2, C742.2, C743.2, C744.2, C926.1, D601.4 (VDD), D602.4 (VDD), D603.4 (VDD), D604.4 (VDD), D605.4 (VDD), D606.4 (VDD), D607.4 (VDD), D608.4 (VDD), D609.4 (VDD), D610.4 (VDD), D611.4 (VDD), D612.4 (VDD), D613.4 (VDD), D614.4 (VDD), D615.4 (VDD), D616.4 (VDD), D617.4 (VDD), D618.4 (VDD), D619.4 (VDD), D620.4 (VDD), D621.4 (VDD), D622.4 (VDD), D623.4 (VDD), D624.4 (VDD), D625.4 (VDD), D626.4 (VDD), D627.4 (VDD), D628.4 (VDD), D629.4 (VDD), D630.4 (VDD), D631.4 (VDD), D632.4 (VDD), D633.4 (VDD), D634.4 (VDD), D635.4 (VDD), D636.4 (VDD), D637.4 (VDD), D638.4 (VDD), D639.4 (VDD), D640.4 (VDD), D641.4 (VDD), D642.4 (VDD), D643.4 (VDD), D644.4 (VDD), D645.4 (VDD), D646.4 (VDD), D647.4 (VDD), D648.4 (VDD), D649.4 (VDD), D650.4 (VDD), D651.4 (VDD), D652.4 (VDD), D653.4 (VDD), D654.4 (VDD), D655.4 (VDD), D656.4 (VDD), D657.4 (VDD), D658.4 (VDD), D659.4 (VDD), D660.4 (VDD), D661.4 (VDD), D662.4 (VDD), D663.4 (VDD), D664.4 (VDD), D665.4 (VDD), D666.4 (VDD), D667.4 (VDD), D668.4 (VDD), D669.4 (VDD), D670.4 (VDD), D671.4 (VDD), D672.4 (VDD), D673.4 (VDD), D674.4 (VDD), D675.4 (VDD), D676.4 (VDD), D677.4 (VDD), D678.4 (VDD), D679.4 (VDD), D680.4 (VDD), D681.4 (VDD), D682.4 (VDD), D683.4 (VDD), D684.4 (VDD), D685.4 (VDD), D686.4 (VDD), D687.4 (VDD), D688.4 (VDD), D689.4 (VDD), D690.4 (VDD), D691.4 (VDD), D692.4 (VDD), D693.4 (VDD), D694.4 (VDD), D695.4 (VDD), D696.4 (VDD), D697.4 (VDD), D698.4 (VDD), D699.4 (VDD), D700.4 (VDD), D701.4 (VDD), D702.4 (VDD), D703.4 (VDD), D704.4 (VDD), D705.4 (VDD), D706.4 (VDD), D707.4 (VDD), D708.4 (VDD), D709.4 (VDD), D710.4 (VDD), D711.4 (VDD), D712.4 (VDD), D713.4 (VDD), D714.4 (VDD), D715.4 (VDD), D716.4 (VDD), D717.4 (VDD), D718.4 (VDD), D719.4 (VDD), D720.4 (VDD), D721.4 (VDD), D722.4 (VDD), D723.4 (VDD), D724.4 (VDD), D725.4 (VDD), D726.4 (VDD), D727.4 (VDD), D728.4 (VDD), D729.4 (VDD), D730.4 (VDD), D731.4 (VDD), D732.4 (VDD), D733.4 (VDD), D734.4 (VDD), D735.4 (VDD), D736.4 (VDD), D737.4 (VDD), D738.4 (VDD), D739.4 (VDD), D740.4 (VDD), D741.4 (VDD), D742.4 (VDD), D743.4 (VDD), D744.4 (VDD), J601.4, J602.4

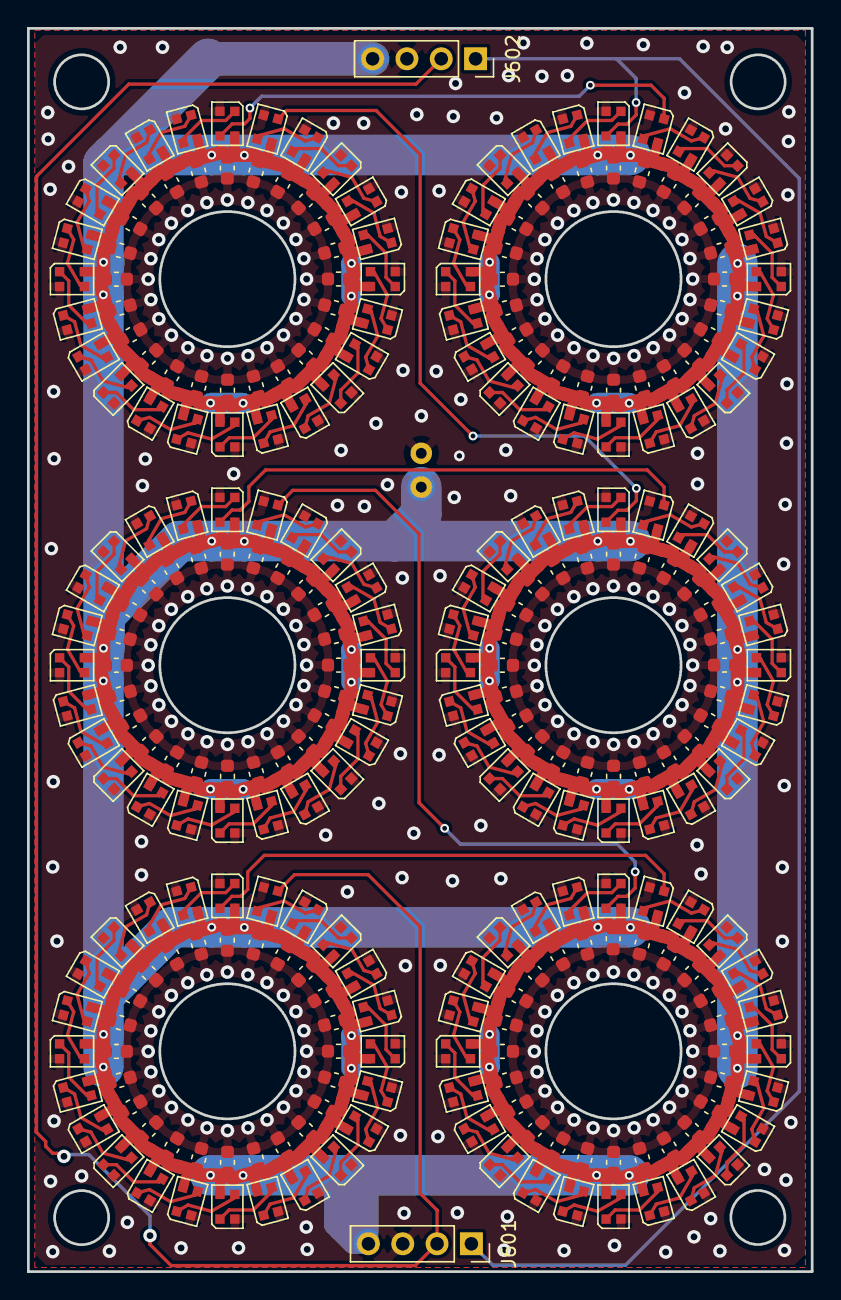
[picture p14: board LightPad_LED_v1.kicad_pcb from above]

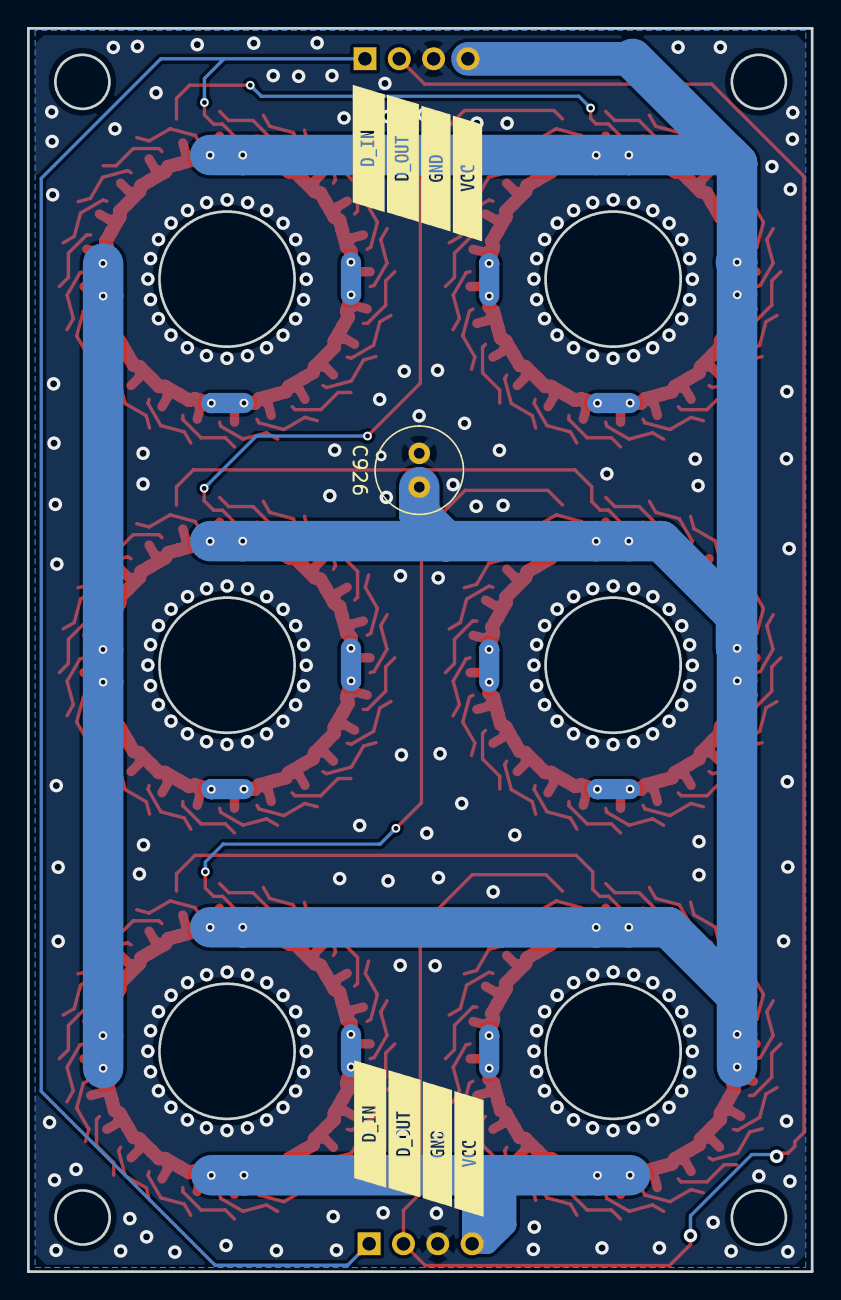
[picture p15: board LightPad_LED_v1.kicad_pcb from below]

Board: 2 copper layers, 58.0 x 92.0 mm, 299 parts (9 on the bottom side), 147 nets.

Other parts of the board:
kibuzzard-6880EE7E, kibuzzard-6880EE7E#2: G***; kibuzzard-6880EE7E
kibuzzard-6880EE9A, kibuzzard-6880EE9A#2: G***; kibuzzard-6880EE9A
kibuzzard-6880EEC9, kibuzzard-6880EEC9#2: G***; kibuzzard-6880EEC9
kibuzzard-6880EEE5, kibuzzard-6880EEE5#2: G***; kibuzzard-6880EEE5

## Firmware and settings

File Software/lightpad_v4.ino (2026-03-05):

// -------------------- Konfiguration -------------------------------------------------------------------------------------

  #include <Wire.h>
  #include <Adafruit_MCP23X17.h>
  #include <WS2812Serial.h>
  #define FASTLED_OVERCLOCK 1.2
  #define FASTLED_ALLOW_INTERRUPTS 1
  #define FASTLED_INTERRUPT_RETRY_COUNT 4
  #define FASTLED_OVERCLOCK_SUPPRESS_WARNING
  #include <FastLED.h>
  #include <WS2812Serial.h>
  #include "Adafruit_DRV2605.h"
  #include <Control_Surface.h>
  #define IR_INPUT_PIN 33
  #include "TinyIRReceiver.hpp"

  Adafruit_MCP23X17 mcp[8];
  #define MCP_COUNT 8
  USBMIDI_Interface midi;
  Adafruit_DRV2605 drv;
  // ---- DRV2605 low-level read/write ----
  #define DRV2605_ADDR 0x5A
  #define REG_STATUS 0x00
  #define REG_MODE 0x01
  #define REG_FEEDBACK 0x1A  // Bit7 selects LRA(1)/ERM(0)
  #define REG_CONTROL3 0x1D  // enthält ERM_OpenLoop-Bit
  #define REG_RATED_VOLTAGE 0x16
  #define REG_OVERDRIVE_CLAMP 0x17


// -------------------- MIDI-CONFIG -----------------------------------------------------------------------------------------

  //const MIDIAddress note = MIDI_Notes::C[4]; // C4 is middle C
  const uint8_t velocity = 127;      // 127 is maximum velocity -> value
  constexpr uint8_t BASE_NOTE = 60;  // C4
  cs::Channel CHANNEL_switch = cs::Channel{ 0 };

  // Hilfsfunktion: Note-Adresse für einen Encoder berechnen
  static inline cs::MIDIAddress encoderAddr(uint8_t row, uint8_t enc_i, uint8_t base, auto channel_x) {
    // row: 1..3, enc_i: 0..7 -> 8 Noten je Reihe
    uint8_t note = base + (row - 1) * 8 + enc_i;  // achte auf 0..127
    return cs::MIDIAddress{ note, channel_x };
  }
  static inline cs::MIDIAddress encoderAddr_2(uint8_t row, uint8_t enc_i, uint8_t base, auto channel_x) {
    // row: 1..3, enc_i: 0..7 -> 8 Noten je Reihe
    uint8_t note = base + (row - 1) * 16 + enc_i;  // achte auf 0..127
    return cs::MIDIAddress{ note, channel_x };
  }
  inline void decodeCC(uint8_t cc, uint8_t &row, uint8_t &enc_i) {
    uint8_t offset = cc - BASE_NOTE;  // 0..23
    row = (offset / 8) + 1;           // 1..3
    enc_i = offset % 8;               // 0..7
  }

// -------------------- LED-CONFIG -------------------------------------------------------------------------------------------

  #define NUM_LEDS_main 64
  #define NUM_LEDS_enc 576
  #define NUM_LEDS_enc_back 96
  #define DATA_PIN_main 1
  #define DATA_PIN_enc 8
  #define DATA_PIN_enc_back 17
  const int colorOrder = WS2812_GRB;

  byte drawingMemory1[NUM_LEDS_enc * 3] = { 0 };
  DMAMEM byte displayMemory1[NUM_LEDS_enc * 12] = { 0 };
  byte drawingMemory2[NUM_LEDS_main * 3] = { 0 };
  DMAMEM byte displayMemory2[NUM_LEDS_main * 12] = { 0 };
  byte drawingMemory3[NUM_LEDS_enc_back * 3] = { 0 };
  DMAMEM byte displayMemory3[NUM_LEDS_enc_back * 12] = { 0 };
  WS2812Serial led_enc(NUM_LEDS_enc, displayMemory1, drawingMemory1, DATA_PIN_enc, colorOrder);
  WS2812Serial led_eb(NUM_LEDS_enc_back, displayMemory3, drawingMemory3, DATA_PIN_enc_back, colorOrder);
  WS2812Serial led_rest(NUM_LEDS_main, displayMemory2, drawingMemory2, DATA_PIN_main, colorOrder);

  uint32_t color_back, color_main, color_rgb, color_rgb2, cl_wh, cl_wh_dimm, color_main_bright, color_back_bright, color_rain, color_back_gr, color_back_bright_gr,color_var_hell,col_l,col_r,col_m, color_back_clipping;
  constexpr uint32_t c_wh_dimm = 0x303030;
  constexpr uint32_t c_wh_bright = 0xFFFFFF;
  constexpr uint32_t c_blu = 0x0000FF;
  int max_power_back_dimm = 50;  //init wert
  int max_power_back = 15;       //init wert
  uint8_t max_hell_power = 255;
  uint8_t max_hell_usb = 60;
  uint8_t color_shift_my = 0;
  uint8_t color_clipping_hue = 0;
  uint8_t color_shift_rain = 0;
  uint8_t hell_up_down = 15;
  uint8_t delta_var = 1;
  uint8_t delta_var_clip =1;
  constexpr uint8_t HUES_enc[8] = { 0, 16, 33, 96, 134, 160, 194, 222 };  // Farben: Rot, Orange, Gelb, Grün, Aqua, Blau, Lila, Magenta
  constexpr bool enc_upper[24] = { 1, 1, 1, 1, 0, 0, 0, 0, 0, 0, 0, 0, 0, 0, 0, 0, 0, 0, 0, 0, 0, 1, 1, 1 };
  constexpr bool enc_lower[24] = { 0, 0, 0, 0, 0, 0, 0, 0, 0, 1, 1, 1, 1, 1, 1, 1, 0, 0, 0, 0, 0, 0, 0, 0 };
  constexpr bool enc_left[24] = { 0, 0, 0, 1, 1, 1, 1, 1, 1, 1, 0, 0, 0, 0, 0, 0, 0, 0, 0, 0, 0, 0, 0, 0 };
  constexpr bool enc_right[24] = { 0, 0, 0, 0, 0, 0, 0, 0, 0, 0, 0, 0, 0, 0, 0, 1, 1, 1, 1, 1, 1, 1, 0, 0 };
  constexpr bool enc_mid[24] = { 0, 0, 0, 0, 1, 1, 1, 1, 1, 0, 0, 0, 0, 0, 0, 0, 1, 1, 1, 1, 1, 0, 0, 0 };
  constexpr bool enc_korn[24] = { 1, 1, 0, 0, 0, 1, 1, 1, 0, 0, 0, 1, 1, 1, 0, 0, 0, 1, 1, 1, 0, 0, 0, 1 };
  constexpr bool enc_unrg[24] = { 0, 0, 1, 1, 1, 1, 1, 1, 1, 0, 0, 1, 1, 1, 1, 0, 1, 1, 1, 0, 1, 1, 0, 1 };
  constexpr uint8_t led_rev[24] = { 0, 23, 22, 21, 20, 19, 18, 17, 16, 15, 14, 13, 12, 11, 10, 9, 8, 7, 6, 5, 4, 3, 2, 1 };  //constexpr uint8_t led_rev[24] = {0,1,2,3,4,5,6,7,8,9,10,11,12,13,14,15,16,17,18,19,20,21,22,23};
  constexpr bool enc_corner[24] = { 0, 0, 1, 1, 1, 0, 0, 0, 1, 1, 1, 0, 0, 0, 1, 1, 1, 0, 0, 0, 1, 1, 1, 0 };
  uint8_t pattern[24];
  constexpr uint8_t N_RING = 24;
  static uint8_t ramp_200_to_0[N_RING];
  static uint8_t ramp_255_to_0[N_RING];
  static uint8_t ramp_255_to_70[N_RING];
  static uint8_t ramp_200_to_130[N_RING];
  static uint8_t ramp_255_to_20[N_RING];
  static uint8_t ramp_255_to_10[N_RING];
  static uint8_t ramp_255_to_120[N_RING];


// -------------------- VARIABLEN-REST --------------------------------------------------------------------------------------

  elapsedMillis since_last_led_change;
  elapsedMillis since_last_led;
  elapsedMillis since_last_counter;
  long since_last_touch = 0;
  bool idle_b_prev=false;
  constexpr int interval_touched = 10000;
  constexpr int interval_blink = 2000;
  constexpr int interval_show = 25;
  constexpr int interval_col_btn = 6;
  bool idle_b = false;
  bool touched_b = false;
  bool ledState = LOW;
  int loop_counter = 0;
  long loop_timer = 0;
  uint32_t fx_fx = 1;
  bool last_button1, last_button2;
  volatile bool rubber_button_changed[3][2] = { false };  //INT
  bool button_state[3][16] = { false };
  constexpr uint8_t UNUSED = 255;
  constexpr const uint8_t CHIP_OF_PCB[3] = { 6, 7, 0 };  //main, key, nav
  constexpr const uint8_t KEY_COUNT[3] = { 16, 16, 8 };  // NAV hat 8 normale Keys + 5 Sonderkeys (9..13)
  constexpr const uint8_t LED_shift[3] = { 0, 48, 16 };
  uint8_t sth_changed = true;  //damit dfirekt gezeichnet wird
  uint16_t IR_aAddress;
  uint8_t IR_aCommand;
  bool IR_isRepeat;
  bool is_prev=false;
  auto channel_ir = cs::Channel{ 9 };
  auto addr_ir_0 = cs::MIDIAddress{ 0, channel_ir };
  auto addr_ir_1 = cs::MIDIAddress{ 1, channel_ir };
  auto addr_ir_2 = cs::MIDIAddress{ 2, channel_ir };
  auto addr_ir_3 = cs::MIDIAddress{ 3, channel_ir };
  auto addr_ir_4 = cs::MIDIAddress{ 4, channel_ir };
  auto addr_ir_5 = cs::MIDIAddress{ 5, channel_ir };
  auto addr_ir_6 = cs::MIDIAddress{ 6, channel_ir };
  auto addr_ir_7 = cs::MIDIAddress{ 7, channel_ir };
  auto addr_ir_8 = cs::MIDIAddress{ 8, channel_ir };
  auto addr_ir_9 = cs::MIDIAddress{ 9, channel_ir };
  uint8_t main_mode = 0;
  static uint32_t lastStepUs_nav = 0;

  constexpr uint8_t led_key[16] = { 0, 1, 2, 3,
                                    7, 6, 5, 4,
                                    8, 9, 10, 11,
                                    15, 14, 13, 12 };

  constexpr uint8_t led_nav[8] = {0,      1,
                                  31,     26,  //24 leds für weiteren encoder dazwischen
                                  30,29,28,27,};

  constexpr uint8_t led_nav_enc[4] = { 2, 8, 14, 20 };

  constexpr uint8_t led_main[16] = { 0, 1, 2, 3, 4, 5, 6, 7,  //von 0..16 beim durchgehen, welcher pin
                                    8, 9, 10, 11, 12, 13, 14, 15 };



  constexpr uint8_t but_key[16] = { 8, 9, 10, 11,  //von 0..16 beim durchgehen, welcher pin
                                    12, 13, 14, 15,
                                    0, 1, 2, 3,
                                    4, 5, 6, 7 };

  constexpr uint8_t but_nav[16] = { UNUSED, 6, 5, 4, 2, 0, 1, UNUSED, UNUSED, 9, 10, 11, 12, 13, 3, 7 };  //links oben nach rechts unten    //navigation encoder->  9mid  10up  12down  11left  13right  //enca 3(0)  encb 8(8)

  constexpr uint8_t but_main[16] = { 4, 5, 6, 7, 15, 14, 13, 12, 11, 10, 9, 8, 0, 1, 2, 3 };  //links oben nach rechts unten

  constexpr const uint8_t *B2K[3] = { but_main, but_key, but_nav };
  constexpr const uint8_t *K2L_u8[3] = { led_main, led_key, led_nav };

  const int MIN_VALUE = 0;
  const int MAX_VALUE = 508;  //anpassen led min max

  const int MIN_VALUE_nav = 0;
  const int MAX_VALUE_nav = 400;  //anpassen led min max
  int counter_nav = { 0 };
  int counter_last_nav = { 0 };
  int counter_last_nav_midi = 0;
  uint8_t lastAB_nav = { 0 };
  volatile bool nav_changed = { false };
  constexpr uint8_t DEBOUNCE_MS = 10;  // 5–10 ms passt meist
  static bool debounce_pending[3] = { false, false, false };
  static uint32_t debounce_due[3] = { 0, 0, 0 };
  static uint16_t debounce_snap1[3] = { 0xFFFF, 0xFFFF, 0xFFFF };




// -------------------- VARIABLEN-ENCODER -----------------------------------------------------------------------------------

  // MCP-Pins für Encoder-Kanal A/B
  constexpr uint8_t enc_rot_pins_A[8] = { 6, 4, 2, 0, 15, 13, 11, 9 };
  constexpr uint8_t enc_rot_pins_B[8] = { 7, 5, 3, 1, 14, 12, 10, 8 };
  // MCP-Pins für Buttons der encoder
  constexpr uint8_t enc_but_pins_4[8] = { 7, 6, 5, 4, 3, 2, 1, 0 };
  constexpr uint8_t enc_but_pins_5[16] = { 15, 14, 13, 12, 11, 10, 9, 8, 7, 6, 5, 4, 3, 2, 1, 0 };
  // Teensy-INT-Pins
  constexpr uint8_t mcpIntA[8] = { 21, 23, 41, 36, 38, 32, 28, 30 };
  constexpr uint8_t mcpIntB[8] = { 20, 22, 40, 35, 37, 31, 27, 29 };

  constexpr uint16_t enc_led[3][8] = { { 24, 0, 168, 144, 312, 288, 456, 432 },
                                      { 72, 48, 216, 192, 360, 336, 504, 480 },
                                      { 120, 96, 264, 240, 408, 384, 552, 528 } };

  constexpr uint8_t enc_used_licht[3][8] = { { 1, 1, 0, 1, 1, 0, 1, 1 },
                                            { 0, 0, 0, 1, 1, 0, 1, 1 },
                                            { 1, 1, 0, 1, 1, 0, 1, 1 } };

  constexpr uint8_t enc_used_details[3][8] = { { 1, 0, 1, 1, 0, 1, 0, 1 },
                                              { 1, 0, 1, 1, 0, 1, 0, 1 },
                                              { 1, 0, 1, 1, 0, 1, 0, 1 } };

  constexpr uint8_t enc_used_cg[3][8] = { { 1, 0, 1, 0, 1, 0, 1, 1 },
                                          { 1, 0, 1, 0, 1, 0, 1, 1 },
                                          { 1, 0, 1, 0, 1, 0, 1, 1 } };

  constexpr uint8_t NUM_ENCODER_CHIPS = 3 + 1;
  constexpr uint8_t ENC_PER_CHIP = 8;
  bool enc_dirty = false;
  uint8_t enc_mode = 0;
  constexpr uint8_t MAX_MODES = 4;
  volatile bool encoderChanged[NUM_ENCODER_CHIPS][2] = { false };
  volatile bool button_changed[NUM_ENCODER_CHIPS][2] = { false };
  int counter[MAX_MODES][NUM_ENCODER_CHIPS][ENC_PER_CHIP] = { 0 };
  int counter_last[MAX_MODES][NUM_ENCODER_CHIPS][ENC_PER_CHIP] = { 0 };
  bool button_enc_last[NUM_ENCODER_CHIPS][ENC_PER_CHIP * 2] = { false };
  int counter_last_midi[MAX_MODES][NUM_ENCODER_CHIPS][ENC_PER_CHIP] = { 0 };
  uint8_t lastAB[NUM_ENCODER_CHIPS][ENC_PER_CHIP] = { 0 };
  // pro Encoder die Zeit der letzten Flanke merken
  static uint32_t lastStepUs[NUM_ENCODER_CHIPS][ENC_PER_CHIP] = { { 0 } };
  // simple Wheel-Acceleration (Grenzen gerne feinjustieren)
  // Quadratur-Übergangstabelle (prev<<2 | curr) -> delta
  // +1: 00->01->11->10->00,  -1: umgekehrt, 0: ungültig/Prell
  static constexpr int8_t quadLUT[16] = {
    0, -1, +1, 0,
    +1, 0, 0, -1,
    -1, 0, 0, +1,
    0, +1, -1, 0
  };


// -------------------- ENCODER-HANDLE ---------------------------------------------------------------------------------------
  static inline uint8_t accelMultiplier(uint32_t dt_us) {
    if (dt_us < 1800) return 8;  // <1.0 ms pro Flanke -> sehr schnell
    if (dt_us < 2400) return 4;  // <2.5 ms
    if (dt_us < 2800) return 2;  // <6.0 ms
    return 1;                    // sonst normal
  }

  void encoder_handle() {
    for (uint8_t row = 1; row <= 3; ++row) {
      if (encoderChanged[row][0] || encoderChanged[row][1]) {  //eine der beiden bänke hat int getriggert
        encoderChanged[row][0] = false;
        encoderChanged[row][1] = false;
        since_last_touch = millis();
        idle_b = false;
        touched_b = true;
        uint16_t gpio = mcp[row].readGPIOAB();  //alle pins vom mcp auslesen

        for (uint8_t enc_i = 0; enc_i < ENC_PER_CHIP; ++enc_i) {
          uint8_t a = bitRead(gpio, enc_rot_pins_A[enc_i]);
          uint8_t b = bitRead(gpio, enc_rot_pins_B[enc_i]);
          uint8_t curr = (a << 1) | b;
          uint8_t prev = lastAB[row][enc_i];

          int8_t delta = quadLUT[(prev << 2) | curr];  // -1,0,+1 pro Flanke

          if (delta) {
            // Encoder 4..7 haben invertierte Richtung
            int8_t dir = (enc_i > 3) ? -1 : +1;  //richtung invertieren
            // Zeit seit letzter Flanke messen
            uint32_t now = micros();
            uint32_t dt = lastStepUs[row][enc_i] ? (now - lastStepUs[row][enc_i]) : 0xFFFFFFFF;
            lastStepUs[row][enc_i] = now;
            uint8_t mult = accelMultiplier(dt);

            counter[enc_mode][row][enc_i] += dir * delta * mult;

            // Begrenzen
            if (counter[enc_mode][row][enc_i] > MAX_VALUE) counter[enc_mode][row][enc_i] = MAX_VALUE;
            if (counter[enc_mode][row][enc_i] < MIN_VALUE) counter[enc_mode][row][enc_i] = MIN_VALUE;

            //midi senden wenn änderung groß genug -> eine rastung
            uint8_t v = counter[enc_mode][row][enc_i] / 4;
            if (v != counter_last_midi[enc_mode][row][enc_i]) {
              counter_last_midi[enc_mode][row][enc_i] = v;
              auto addr = encoderAddr(row, enc_i, BASE_NOTE, CHANNEL_switch);
              midi.sendControlChange(addr, v);
              //Serial.printf("row=%u enc=%u cc=%u val=%u\n", row, enc_i, addr.getAddress(), v);
              //Serial.printf("Counter: %d,   Counter/4: %d,  mult: %d \n", counter[enc_mode][row][enc_i], counter[enc_mode][row][enc_i]/4, mult);
            }
          }
          lastAB[row][enc_i] = curr;
        }
        mcp[row].clearInterrupts();
      }
    }
  }
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
  void loop() {
    // put your main code here, to run repeatedly:
    led_blink();

    if (main_mode == 0) {
      if(millis()-since_last_touch > interval_touched){
        idle_b = true;
        idle_b_prev = true;
      }  
      encoder_handle();
      encoder_button_handle();
      handle_rest();
      if(idle_b){
        main_mode = 2;
      }
      else{
        update_my();    
      }
      midi.update();
    } 
    else if (main_mode == 1) {
      //led show
      pride();
      color_shift_rain++; 
      rainbow();
      led_eb.show();
      jump_back();
    }
    else if (main_mode == 2) {
      //led show
      color_shift_rain++; 
      runIdleTwinkles();
      rainbow();
      led_eb.show();
      led_enc.show();
      jump_back();
    }
    else if (main_mode == 3)  {
      //led show
      color_shift_rain++; 
      runIdleStarlight();
      rainbow();
      led_eb.show();
      jump_back();
    }
  }





// --------------------------------------------------------------------------------------------------------------------------
